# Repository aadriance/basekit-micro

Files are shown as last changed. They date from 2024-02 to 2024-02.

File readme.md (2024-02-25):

# Basekit-Micro

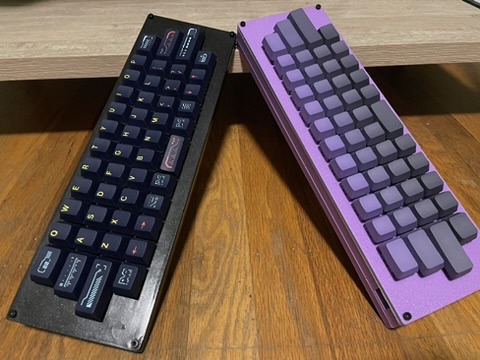
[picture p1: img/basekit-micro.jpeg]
basekit-micro


Basekit-micro is a 40% keyboard that uses a pro micro and a standard 60% base
kit for it's keys. Want to use a cool keyset and a planck layout? basekit is
here for you!

## Fair Warning

This is my first PCB design. I have built 3 PCBs of this and used them for a
year without issue, that doesn't mean it's perfect. I don't recommend using
it unless you have experience making PCBs from open source repos.

## Making it

- Visit the PCB folder to get the PCB produced.
- Visit the firmware folder to make your layout, or use mine.
- Visit the case folder and choose a case configuration.
- Enjoy.

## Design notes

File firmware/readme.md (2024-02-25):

# Firmware

- A pre-compiled hex for my personal layout is provided to help kitstart.
- I have decided to not commit basekit-micro to qmk proper since I won't be
making additional versions or PCBs at this point.
- You can find my firmware in a [personal QMK branch here](https://github.com/aadriance/qmk_firmware/tree/basekitmicro/keyboards/basekitmicro)

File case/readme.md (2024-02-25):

# Case
The case comes in two variants:

- Chonky, the original case I designed.
- AIO, a nicer slimmer case.

You will need:

- A 3D printer with a 300mm build volume, or be willing to print it side ways on
a smaller printer with plenty of supports.
- 4 M3 heated inserts (M3*4.6x5.7mm).
- 4 M3 screws.

I think AIO is better, but Chonky can be nice for it's added color options,
or if you want a nice flat surface on the edges from the 3D print.

To build:

- Print the plate stl.
- Print the base pieces of your chosen design.
- Add heat inserts.
- Use switches to affix PCB to plate.
- Insert M3 screws through plate into heat inserts.
- Enjoy!.

## Chonky VS Aio Cases

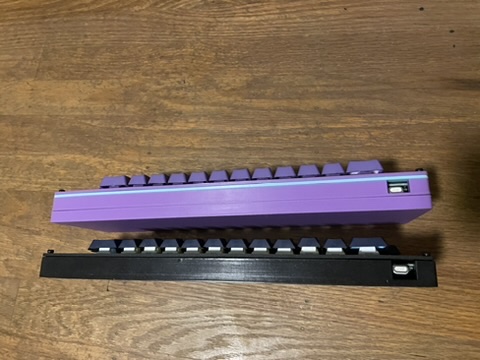
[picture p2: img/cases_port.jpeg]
ports


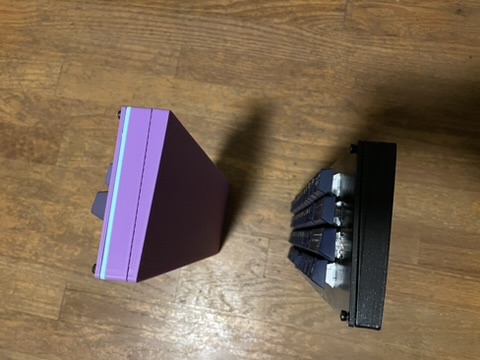
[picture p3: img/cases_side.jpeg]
side


## Notes

- I have printed the case in PLA and PETG without issue.
- If you choose to use stabilizers, depending on the brand they might fit
too tightly in the provided cutouts. Some trimming may be required.

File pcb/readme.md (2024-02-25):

# PCB

- The basekitmicro folder contains the kicad project.
- The jlcpcb folder contains the files I used to get a run made by jlcpcb.

To build the pcb you will need:

- 47 SMD dioides if not using a soldering service. See BOM in jlcpcb folder.
- a pro micro.

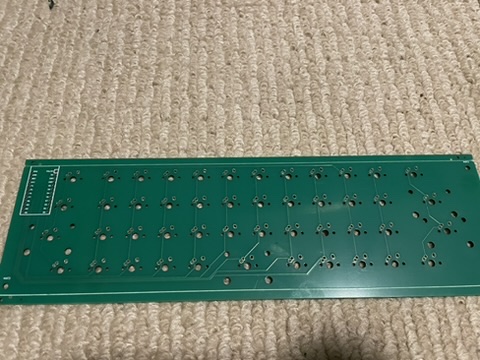
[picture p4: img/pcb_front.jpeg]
front


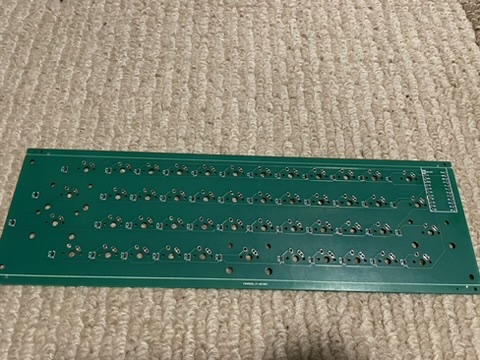
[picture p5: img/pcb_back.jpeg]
back


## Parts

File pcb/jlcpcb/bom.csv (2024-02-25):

Comment | Designator | Footprint | LCSC
D | D_0,D_1,D_2,D_3,D_4,D_5,D_6,D_7,D_8,D_9,D_10,D_11,D_12,D_13,D_14,D_15,D_16,D_17,D_18,D_19,D_20,D_21,D_22,D_23,D_24,D_25,D_26,D_27,D_28,D_29,D_30,D_31,D_32,D_33,D_34,D_35,D_36,D_37,D_38,D_39,D_40,D_41,D_42,D_43,D_44,D_45,D_46 | Diode_SMD:D_SOD-123 | C81598

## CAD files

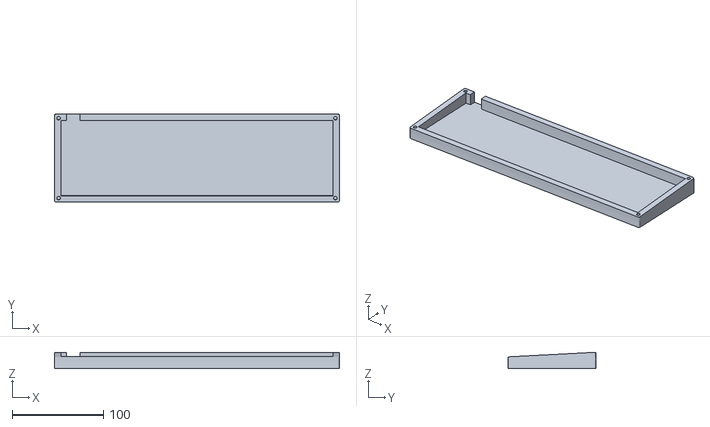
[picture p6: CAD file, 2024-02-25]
case/aio/basekitmicro_aio_bottom.stl
312.0 x 96.8 x 18.0

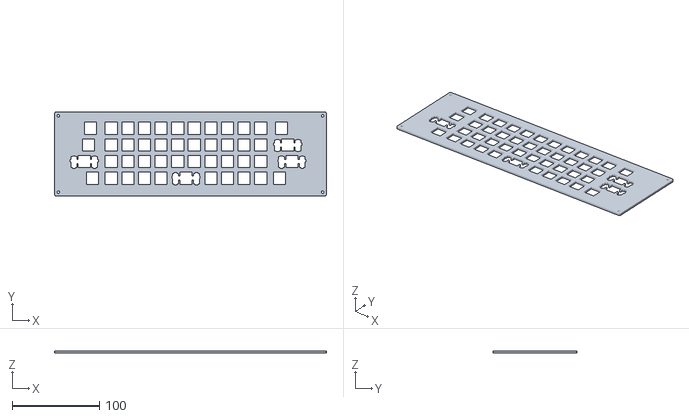
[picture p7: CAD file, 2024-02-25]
case/basekitmicro_plate.stl
312.0 x 96.5 x 2.50

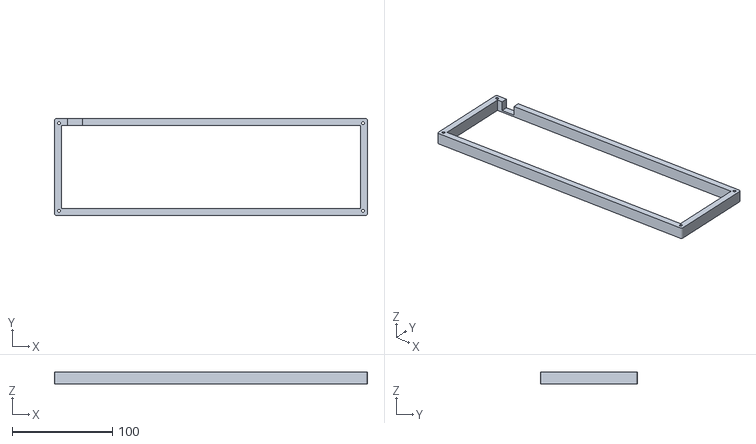
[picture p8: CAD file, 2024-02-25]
case/chonky/basekitmicro_middle.stl
312.0 x 96.5 x 12.0

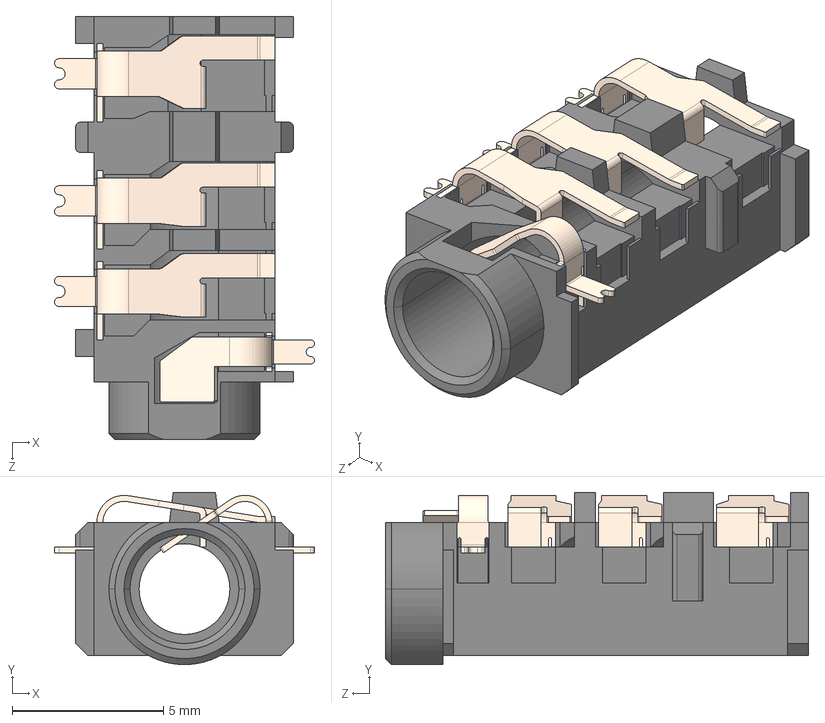
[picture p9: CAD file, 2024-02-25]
pcb/basekitmicro/Keebio-Parts.pretty-master/3dmodels/CUI_SJ-43614-SMT-TR.step
8.60 x 5.70 x 14.0 mm

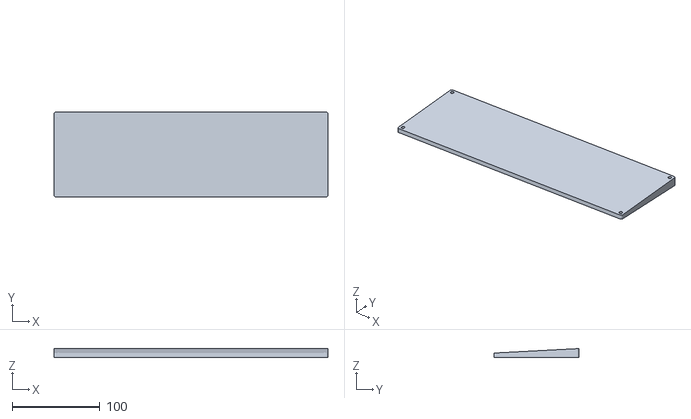
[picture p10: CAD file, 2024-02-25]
case/chonky/basekitmicro_base.stl
312.0 x 96.5 x 10.1

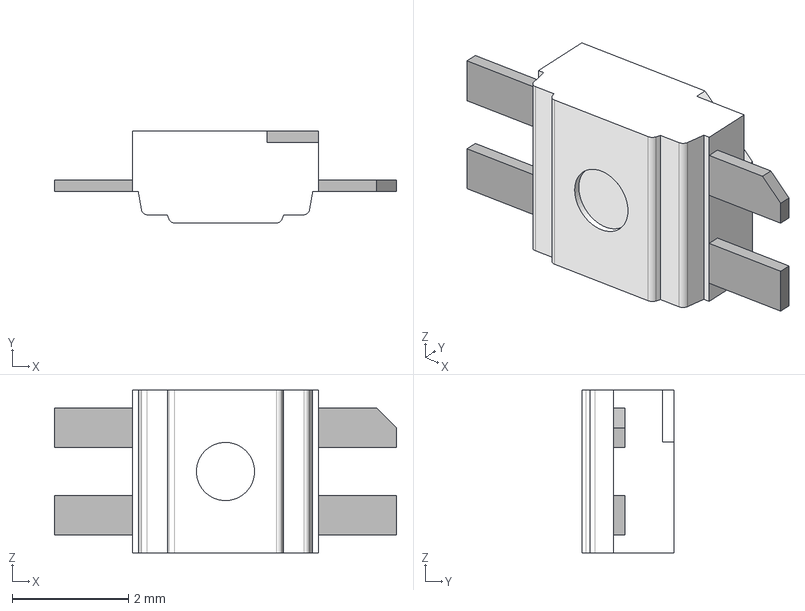
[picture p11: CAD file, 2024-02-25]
pcb/basekitmicro/Keebio-Parts.pretty-master/3dmodels/SK6812MINI-E v1.step
5.88 x 1.58 x 2.80 mm

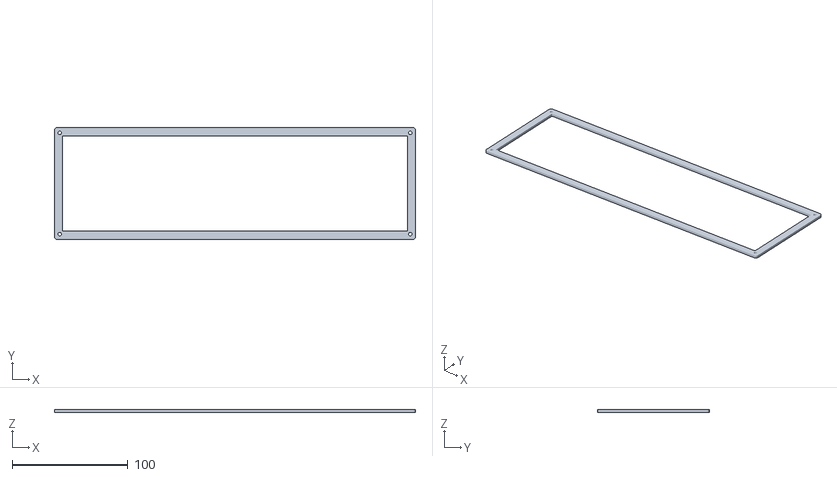
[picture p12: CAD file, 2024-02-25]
case/chonky/basekitmicro_buffer.stl
312.0 x 96.5 x 2.50

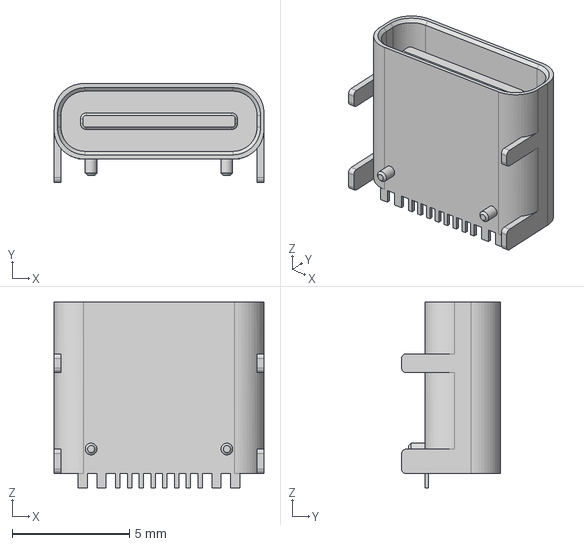
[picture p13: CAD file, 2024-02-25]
pcb/basekitmicro/Keebio-Parts.pretty-master/3dmodels/HRO TYPE-C-31-M-12.step
8.94 x 4.21 x 7.90 mm

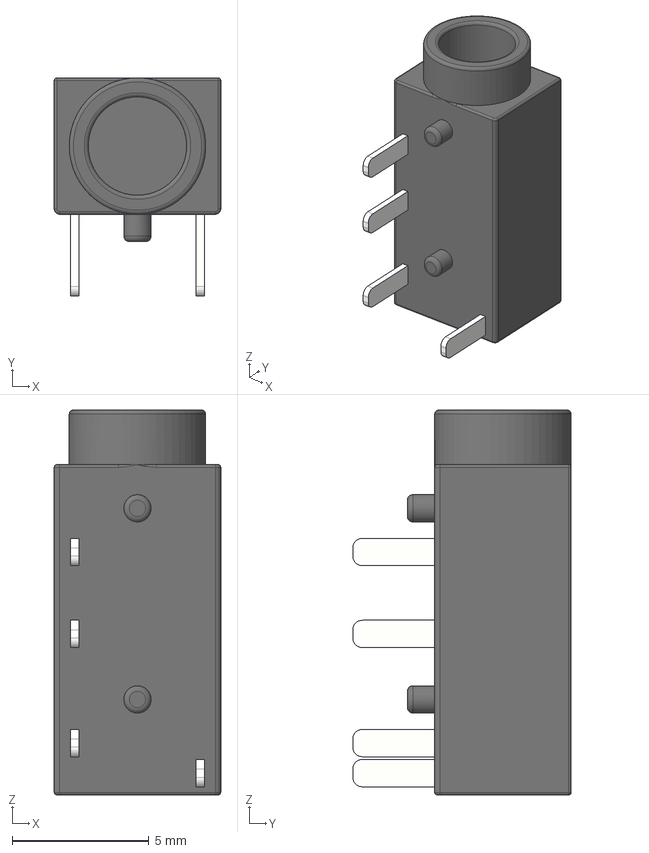
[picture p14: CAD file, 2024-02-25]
pcb/basekitmicro/Keebio-Parts.pretty-master/3dmodels/PJ-320A.step
6.10 x 8.00 x 14.1 mm

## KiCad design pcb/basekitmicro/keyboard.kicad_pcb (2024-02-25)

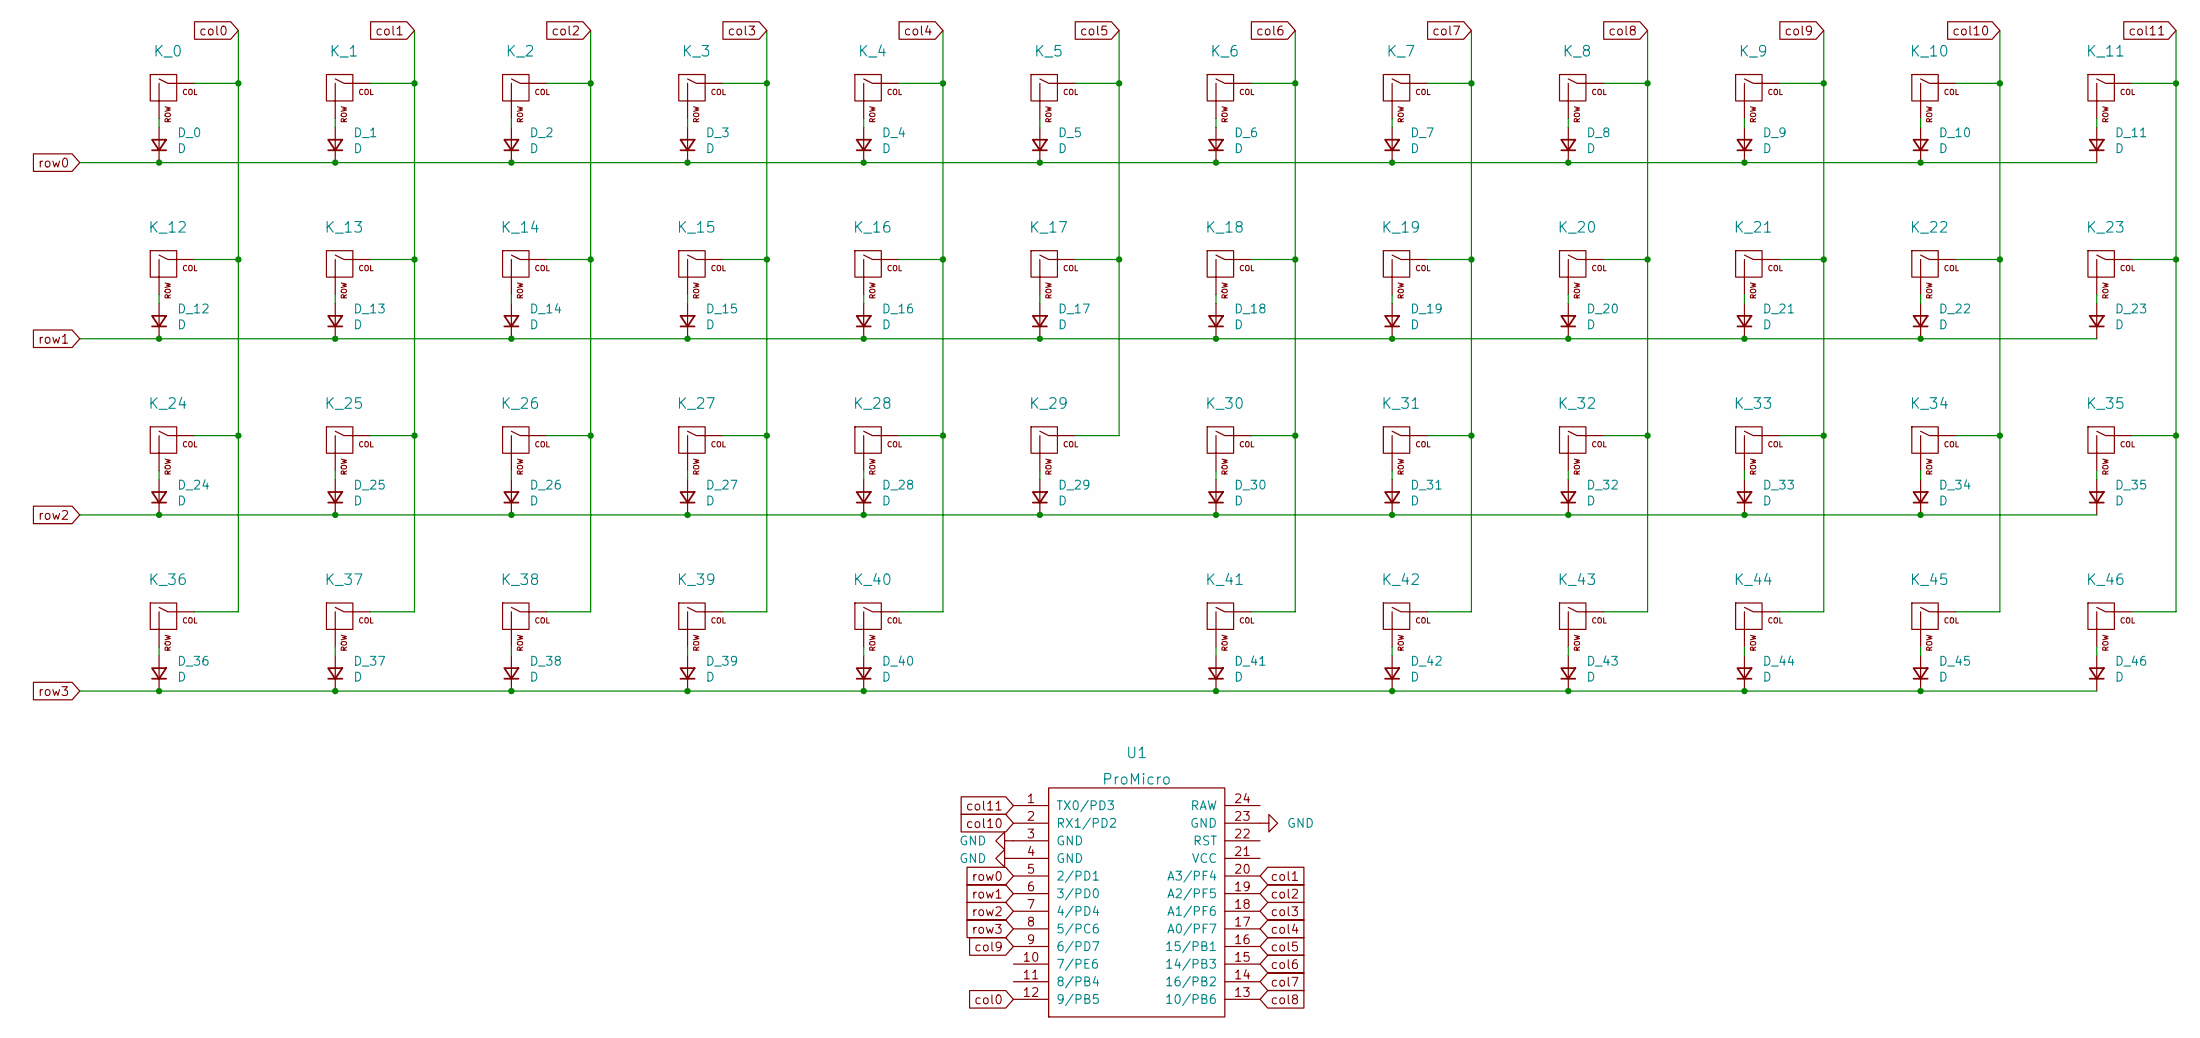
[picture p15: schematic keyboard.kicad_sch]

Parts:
D_0, D_1, D_2, D_3, D_4, D_5, D_6, D_7, D_8, D_9, D_10, D_11, D_12, D_13, D_14, D_15, D_16, D_17, D_18, D_19, D_20, D_21, D_22, D_23, D_24, D_25, D_26, D_27, D_28, D_29, D_30, D_31, D_32, D_33, D_34, D_35, D_36, D_37, D_38, D_39, D_40, D_41, D_42, D_43, D_44, D_45, D_46: D; D_SOD-123
K_0, K_11: KEYSW; MX-1.5U-NoLED
K_1, K_2, K_3, K_4, K_5, K_6, K_7, K_8, K_9, K_10, K_13, K_14, K_15, K_16, K_17, K_18, K_19, K_20, K_21, K_22, K_25, K_26, K_27, K_28, K_29, K_30, K_31, K_32, K_33, K_34, K_37, K_38, K_39, K_40, K_42, K_43, K_44, K_45: KEYSW; MX-1U-NoLED
K_12: KEYSW; MX-1.75U-NoLED
K_23, K_24: KEYSW; MX-2.25U-NoLED
K_35: KEYSW; MX-2.75U-NoLED
K_36, K_46: KEYSW; MX-1.25U-NoLED
K_41: KEYSW; MX-2U-NoLED
U1: ProMicro; ArduinoProMicro

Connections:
GND: U1.3 (GND), U1.4 (GND), U1.23 (GND)
unnamed: D_0.2 (A), K_0.2 (ROW)
unnamed: D_1.2 (A), K_1.2 (ROW)
unnamed: D_2.2 (A), K_2.2 (ROW)
unnamed: D_3.2 (A), K_3.2 (ROW)
unnamed: D_4.2 (A), K_4.2 (ROW)
unnamed: D_5.2 (A), K_5.2 (ROW)
unnamed: D_6.2 (A), K_6.2 (ROW)
unnamed: D_7.2 (A), K_7.2 (ROW)
unnamed: D_8.2 (A), K_8.2 (ROW)
unnamed: D_9.2 (A), K_9.2 (ROW)
unnamed: D_10.2 (A), K_10.2 (ROW)
unnamed: D_11.2 (A), K_11.2 (ROW)
unnamed: D_12.2 (A), K_12.2 (ROW)
unnamed: D_13.2 (A), K_13.2 (ROW)
unnamed: D_14.2 (A), K_14.2 (ROW)
unnamed: D_15.2 (A), K_15.2 (ROW)
unnamed: D_16.2 (A), K_16.2 (ROW)
unnamed: D_17.2 (A), K_17.2 (ROW)
unnamed: D_18.2 (A), K_18.2 (ROW)
unnamed: D_19.2 (A), K_19.2 (ROW)
unnamed: D_20.2 (A), K_20.2 (ROW)
unnamed: D_21.2 (A), K_21.2 (ROW)
unnamed: D_22.2 (A), K_22.2 (ROW)
unnamed: D_23.2 (A), K_23.2 (ROW)
unnamed: D_24.2 (A), K_24.2 (ROW)
unnamed: D_25.2 (A), K_25.2 (ROW)
unnamed: D_26.2 (A), K_26.2 (ROW)
unnamed: D_27.2 (A), K_27.2 (ROW)
unnamed: D_28.2 (A), K_28.2 (ROW)
unnamed: D_29.2 (A), K_29.2 (ROW)
unnamed: D_30.2 (A), K_30.2 (ROW)
unnamed: D_31.2 (A), K_31.2 (ROW)
unnamed: D_32.2 (A), K_32.2 (ROW)
unnamed: D_33.2 (A), K_33.2 (ROW)
unnamed: D_34.2 (A), K_34.2 (ROW)
unnamed: D_35.2 (A), K_35.2 (ROW)
unnamed: D_36.2 (A), K_36.2 (ROW)
unnamed: D_37.2 (A), K_37.2 (ROW)
unnamed: D_38.2 (A), K_38.2 (ROW)
unnamed: D_39.2 (A), K_39.2 (ROW)
unnamed: D_40.2 (A), K_40.2 (ROW)
unnamed: D_41.2 (A), K_41.2 (ROW)
unnamed: D_42.2 (A), K_42.2 (ROW)
unnamed: D_43.2 (A), K_43.2 (ROW)
unnamed: D_44.2 (A), K_44.2 (ROW)
unnamed: D_45.2 (A), K_45.2 (ROW)
unnamed: D_46.2 (A), K_46.2 (ROW)
col0: K_0.1 (COL), K_12.1 (COL), K_24.1 (COL), K_36.1 (COL), U1.12 (9/PB5)
col1: K_1.1 (COL), K_13.1 (COL), K_25.1 (COL), K_37.1 (COL), U1.20 (A3/PF4)
col2: K_2.1 (COL), K_14.1 (COL), K_26.1 (COL), K_38.1 (COL), U1.19 (A2/PF5)
col3: K_3.1 (COL), K_15.1 (COL), K_27.1 (COL), K_39.1 (COL), U1.18 (A1/PF6)
col4: K_4.1 (COL), K_16.1 (COL), K_28.1 (COL), K_40.1 (COL), U1.17 (A0/PF7)
col5: K_5.1 (COL), K_17.1 (COL), K_29.1 (COL), U1.16 (15/PB1)
col6: K_6.1 (COL), K_18.1 (COL), K_30.1 (COL), K_41.1 (COL), U1.15 (14/PB3)
col7: K_7.1 (COL), K_19.1 (COL), K_31.1 (COL), K_42.1 (COL), U1.14 (16/PB2)
col8: K_8.1 (COL), K_20.1 (COL), K_32.1 (COL), K_43.1 (COL), U1.13 (10/PB6)
col9: K_9.1 (COL), K_21.1 (COL), K_33.1 (COL), K_44.1 (COL), U1.9 (6/PD7)
col10: K_10.1 (COL), K_22.1 (COL), K_34.1 (COL), K_45.1 (COL), U1.2 (RX1/PD2)
col11: K_11.1 (COL), K_23.1 (COL), K_35.1 (COL), K_46.1 (COL), U1.1 (TX0/PD3)
row0: D_0.1 (K), D_1.1 (K), D_2.1 (K), D_3.1 (K), D_4.1 (K), D_5.1 (K), D_6.1 (K), D_7.1 (K), D_8.1 (K), D_9.1 (K), D_10.1 (K), D_11.1 (K), U1.5 (2/PD1)
row1: D_12.1 (K), D_13.1 (K), D_14.1 (K), D_15.1 (K), D_16.1 (K), D_17.1 (K), D_18.1 (K), D_19.1 (K), D_20.1 (K), D_21.1 (K), D_22.1 (K), D_23.1 (K), U1.6 (3/PD0)
row2: D_24.1 (K), D_25.1 (K), D_26.1 (K), D_27.1 (K), D_28.1 (K), D_29.1 (K), D_30.1 (K), D_31.1 (K), D_32.1 (K), D_33.1 (K), D_34.1 (K), D_35.1 (K), U1.7 (4/PD4)
row3: D_36.1 (K), D_37.1 (K), D_38.1 (K), D_39.1 (K), D_40.1 (K), D_41.1 (K), D_42.1 (K), D_43.1 (K), D_44.1 (K), D_45.1 (K), D_46.1 (K), U1.8 (5/PC6)

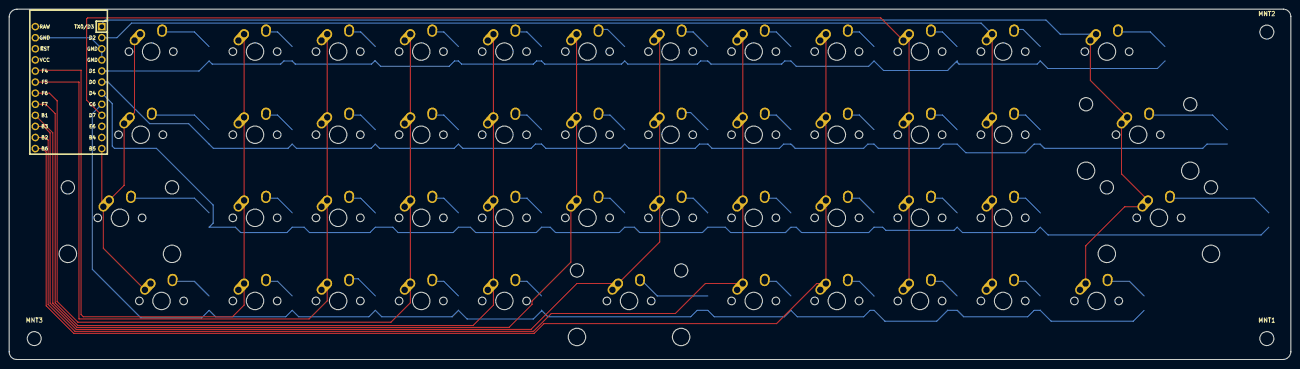
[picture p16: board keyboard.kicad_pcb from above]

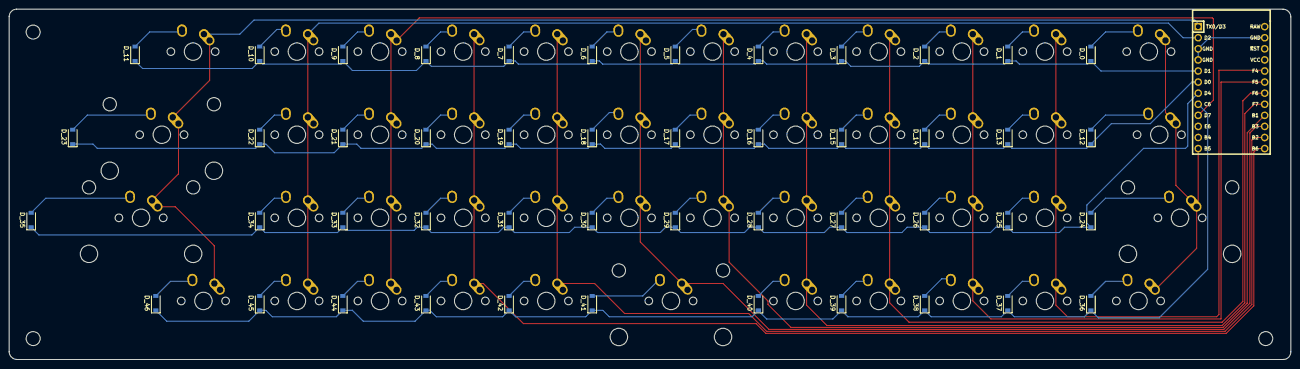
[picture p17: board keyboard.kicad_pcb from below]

Board: 2 copper layers, 293.8 x 80.3 mm, 98 parts (48 on the bottom side), 64 nets.

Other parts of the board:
MNT1, MNT2, MNT3: MountingHole_3.2mm_M3
